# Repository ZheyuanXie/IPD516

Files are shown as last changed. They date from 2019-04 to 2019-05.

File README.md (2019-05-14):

# IPD 516 final project (MIDI & Sync Team)
Zheyuan Xie, Peng Li

## Overview
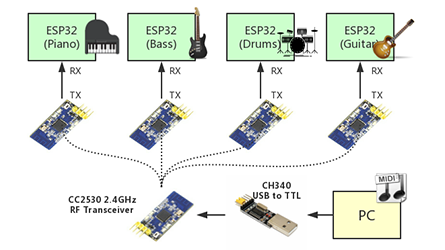
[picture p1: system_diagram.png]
system


## Software
### Dependency
 - pyserial
 - mido
 - remi
 
You can install these packages using pip:
```
pip install pyserial mido remi
```

## Hardware
 - The transmitter module connected to PC sends MIDI bytes to four receiver modules.
 - The receiver modules process the bytes and communicate with the machatronic instrument through a TTL serial interface.

MIDI Transmitter PCB          |  MIDI Receiver PCB
:-------------------------:|:-------------------------:
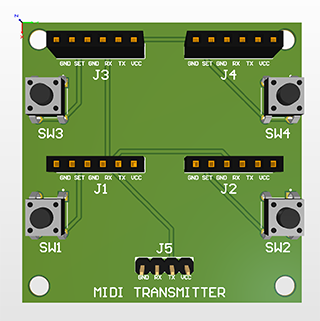
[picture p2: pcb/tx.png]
pcb_rx
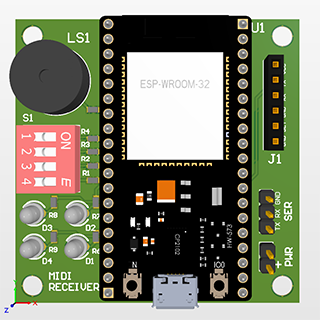
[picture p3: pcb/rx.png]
pcb_tx
      |  

## Instruction for Instrument Teams
As a musical instrument team, you will get a receiver module. You should connect the UART2 port (or another UART port) of your ESP32 to the SER connector (3 male header pins on the right side of the receiver module).

The code that runs on your ESP32 should be derived from `insturment_template.ino`. The four functions you will need to implement are:
 - `init_inst`: Initialize your instrument, run only once when system boots.
 - `note_on`: The response to a MIDI NOTE_ON message. Do not use blocking functions like `delay()` here.
 - `note_off`: The response to a MIDI NOTE_OFF message. Instrument that does not sustain need not to implement this function.
 - `expected_delay`: This function calculates the expected delay between executing the `note_on` and actually generating sound. It can be a constant or a function of note, velocity, and previous note played, depending on the type of your instrument.

The MIDI receiver module issues commands in real time, but in `instrument_template.ino`, each note is delayed `GLOBAL_DELAY - expected_delay()` microseconds to trigger the `note_on` function. The default value of `GLOBAL_DELAY` is **3 seconds**, which should give you enough time to prepare the actuator. Therefore the `expeteced_delay()` should not return a value larger than the `GLOBAL_DELAY`.

### Test your code with MIDI Receiver PCB using USB Serial
For instrument team who want to test their code that derived from `insturment_template.ino`, you should
- Upload `receiver_test.ino` to the ESP32 that will mount on the MIDI Receiver PCB;
- Connect your ESP32 to receiver ESP32;
- Set DIP switch *1* ON to receive message via USB serial;
- Set DIP switch *2* ON to turn the buzzer ON.

Instrument ESP32 | Receiver ESP32
:-----------------:|:----------------:
RX   |TX
TX   |RX
GND|GND
- Connect receiver ESP32 to your computer COM port
- Download `sender` folder and run the python code `main.py` 
- Choose the serial COM Port that receiver ESP32 connects to
- Choose the song that you would like to play
- Map channels as you desired, for example `2:0,9:9` means map MIDI channel 3 to instrument channel 0 and map MIDI channel 10 to instrument channel 9, this also means that only MIDI events from MIDI channel 3 and channel 10 are sent. If you want MIDI messages from all channel to be received, you need to write `0:0,1:1,2:2,3:3,4:4,5:5,6:6,7:7,8:8,9:9,10:10,11:11,12:12,13:13,14:14,15:15`. You can also map 2 or more channel to one channel, `0:0, 2:0` maps MIDI channel 1 and 3 to instrument channel 0.

Now when you hit the start button, the receiver ESP32 should get MIDI events via USB serial and should send MIDI events of channel selected by DIP switch to your instrument ESP32. DIP switch *3* is the most significant bit and *4* is the least significant bit. If *3* is *on*, then instrument channel 2 is selected. If *4* is on, then instrument channel 1 is selected. If *3* and *4* are both on, then instrument channel 3 is selected.

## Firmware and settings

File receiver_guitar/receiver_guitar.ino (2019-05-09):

 
#define PRINT_ERROR Serial.println("Error!");

#define LED_R 13
#define LED_Y 12
#define LED_G 27
#define LED_W 25
#define DIP_SWITCH_1 36
#define DIP_SWITCH_2 39
#define DIP_SWITCH_3 34
#define DIP_SWITCH_4 35
#define GLOBAL_DELAY 4500000  // global delay in microseconds

#include "esp_task_wdt.h"
#include "soc/timer_group_struct.h"
#include "soc/timer_group_reg.h"

//byte cmd[3];
int cnt = 0;
int count =0;
/* structure that hold data*/
typedef struct{
  byte info[3];
  unsigned long receivedTime;
}midiMes;

typedef struct{
  byte note;
  unsigned long receivedOnTime;
}midiMes_guitar;

/* msg queue */
#define MSG_Q_SIZE 128
uint8_t msg_q_bmap[MSG_Q_SIZE];

midiMes cmd;

/* this variable hold queue handle */
xQueueHandle xQueue;
TaskHandle_t xTask1;
TaskHandle_t xTask2;

void setup() {
  memset(msg_q_bmap, 0, sizeof(msg_q_bmap));
  
  Serial.begin(115200);
  Serial1.begin(115200,SERIAL_8N1,26,14);
  Serial2.begin(115200);
  ledcSetup(0, 2000, 8);
  ledcAttachPin(32, 0);
  
  pinMode(LED_R, OUTPUT);
  pinMode(LED_Y, OUTPUT);
  pinMode(LED_G, OUTPUT);
  pinMode(LED_W, OUTPUT);
  pinMode(DIP_SWITCH_1, INPUT);
  pinMode(DIP_SWITCH_2, INPUT);
  pinMode(DIP_SWITCH_3, INPUT);
  pinMode(DIP_SWITCH_4, INPUT);
  
  /* create the queue which size can contains 5 elements of Data */
  xQueue = xQueueCreate(2000, (sizeof(midiMes)));

//  xTaskCreatePinnedToCore(
//      sendTask,           /* Task function. */
//      "sendTask",        /* name of task. */
//      2000,                    /* Stack size of task */
//      NULL,                     /* parameter of the task */
//      1,                        /* priority of the task */
//      &xTask1,                /* Task handle to keep track of created task */
//      1);                    /* pin task to core 0 */
  xTaskCreatePinnedToCore(
      receiveTask,           /* Task function. */
      "receiveTask",        /* name of task. */
      20000,                    /* Stack size of task */
      NULL,                     /* parameter of the task */
      1,                        /* priority of the task */
      &xTask2,            /* Task handle to keep track of created task */
      0);                 /* pin task to core 1 */
}

void loop() {
  if (digitalRead(DIP_SWITCH_1)) {
    digitalWrite(2,HIGH);
    if (Serial.available() > 0) {
      process_incoming_byte(Serial.read());
    }
  } else {
    digitalWrite(2,LOW);
    if (Serial2.available() > 0) {
      process_incoming_byte(Serial2.read()); 
    }
  }    
}

//void sendTask( void * parameter )
//{
//  for(;;){
//    if (Serial2.available() > 0) {
//      Serial.println(Serial2.read());
//      process_incoming_byte(Serial2.read());
//    }
//  }
//}

void receiveTask( void * parameter )
{
  BaseType_t xStatus;
  for(;;)
  {
    midiMes receivedCmd;
  /* keep the status of receiving data */  
    /* receive data from the queue */
    xStatus = xQueueReceive( xQueue, &receivedCmd, 10);
    /* check whether receiving is ok or not */
    if(xStatus == pdPASS){  
      while ((micros() - receivedCmd.receivedTime)<GLOBAL_DELAY){
        //feed the dog
        TIMERG0.wdt_wprotect=TIMG_WDT_WKEY_VALUE;
        TIMERG0.wdt_feed=1;
        TIMERG0.wdt_wprotect=0;
      };        
      process_midi_command(receivedCmd.info);
    }
  }  
  vTaskDelete( NULL );
}

void process_incoming_byte(const byte incoming_byte) {
  if ((uint8_t)incoming_byte > 127) {
    cnt = 0;
    cmd.info[cnt] = (incoming_byte & 0x0f);
  } else if (cnt > 3) {
    PRINT_ERROR;
  } else {
    cnt++;
    cmd.info[cnt] = incoming_byte;
    if (cnt == 2) {
      cmd.receivedTime = micros();
      xQueueSendToBack(xQueue, &cmd, 10);
      if (cmd.info[0] == get_channel()){
        storeInSendQueue();
//        cmd.info[1] = (cmd.info[1] | 0x80);
//        Serial1.write(cmd.info[1]); 
      }
    }
  }
}

midiMes_guitar sendQueue[MSG_Q_SIZE];

int length = 0;
int msg_q_ptr = 0;
byte duration_buf[5];
unsigned long duration;

void storeInSendQueue(){
  if (cmd.info[2]>0){
    for (int i = 0; i <= MSG_Q_SIZE; i++) {
      if (msg_q_bmap[i] == 0) {
        msg_q_bmap[i] = 1;
        sendQueue[i].note = cmd.info[1];
        sendQueue[i].receivedOnTime = micros(); 
        length++;
        break;  
      }else if (i == MSG_Q_SIZE - 1){
//          Serial.printf("Error: message queue is full!\n");
          break;
      }
    }
  }else{
    for(int i = 0; i <= MSG_Q_SIZE; i++)
      if (msg_q_bmap[i] == 1 && sendQueue[i].note == cmd.info[1]) {
        duration = micros() - sendQueue[i].receivedOnTime;
        duration_buf[0] = sendQueue[i].note | 0x80;
        duration_buf[1] = (unsigned long)duration & 0x7F;
        duration_buf[2] = ((unsigned long)duration >> 7)  & 0x7F;
        duration_buf[3] = ((unsigned long)duration >> 14) & 0x7F;
        duration_buf[4] = ((unsigned long)duration >> 21) & 0x7F;
        duration_buf[5] = ((unsigned long)duration >> 28) & 0x7F; 
        Serial1.write(duration_buf,6);      
//        Serial1.write(duration_buf[0]);
//        Serial1.write(duration_buf[1]);
//        Serial1.write(duration_buf[2]);
//        Serial1.write(duration_buf[3]);
//        Serial1.write(duration_buf[4]);
//        Serial1.write(duration_buf[5]);
        msg_q_bmap[i] = 0;
        break;
        length--;  
      }else if (i == MSG_Q_SIZE - 1){
//          Serial.printf("Error: message queue is full!\n");
          break;
      }       
  }
}

uint8_t get_channel() {
  uint8_t res = digitalRead(DIP_SWITCH_3) * 2 + digitalRead(DIP_SWITCH_4);
//  Serial.printf("DIP SWITCH: %d\n", res);
  return res;
}

void process_midi_command(byte MIDI[3]) {
  count = count +1;
  Serial.printf("channel:%d, note:%d, velocity:%d， #get%d.\n\r", MIDI[0], MIDI[1], MIDI[2],count);
  uint8_t channel = MIDI[0];
  uint8_t note = MIDI[1];
  uint8_t vel = MIDI[2];

  // Drumset
  if (channel == 9) {
    if (note > 42 && vel > 0) digitalWrite(LED_R, HIGH);
    if (note > 42 && vel == 0) digitalWrite(LED_R, LOW);
    if (note == 36 && vel > 0) digitalWrite(LED_G, HIGH);
    if (note == 36 && vel == 0) digitalWrite(LED_G, LOW);
    if (note == 40 && vel > 0) digitalWrite(LED_Y, HIGH);
    if (note == 40 && vel == 0) digitalWrite(LED_Y, LOW);
    if (note == 42 && vel > 0) digitalWrite(LED_W, HIGH);
    if (note == 42 && vel == 0) digitalWrite(LED_W, LOW);
  }

  // selected channel
  if (channel == get_channel() && digitalRead(DIP_SWITCH_2)) {
    if (vel > 0) {
      ledcWriteTone(0, note_to_frequency(note));
    } else {
      ledcWriteTone(0, 0);
    }
  }
}

int note_to_frequency(uint8_t note) {
  switch (note) {
    case 36: return 65;
    case 37: return 69;
    case 38: return 73;
    case 39: return 78;
    case 40: return 82;
    case 41: return 87;
    case 42: return 93;
    case 43: return 98;
    case 44: return 104;
    case 45: return 110;
    case 46: return 117;
    case 47: return 123;
    case 48: return 131;
    case 49: return 139;
    case 50: return 147;
    case 51: return 156;
    case 52: return 165;
    case 53: return 175;
    case 54: return 185;
    case 55: return 196;
    case 56: return 207;
    case 57: return 220;
    case 58: return 233;
    case 59: return 247;
    case 60: return 262;
    case 61: return 277;
    case 62: return 294;
    case 63: return 311;
    case 64: return 330;
    case 65: return 349;
    case 66: return 370;
    case 67: return 392;
    case 68: return 415;
    case 69: return 440;
    case 70: return 466;
    case 71: return 494;
    case 72: return 523;
    case 73: return 554;
    case 74: return 587;
    case 75: return 622;
    case 76: return 659;
    case 77: return 698;
    case 78: return 740;
    case 79: return 784;
    case 80: return 831;
    case 81: return 880;
    case 82: return 932;
    case 83: return 988;
    case 84: return 1046;
    case 85: return 1109;
    case 86: return 1175;
    case 87: return 1245;
    case 88: return 1319;
    case 89: return 1397;
    case 90: return 1480;
    case 91: return 1568;
    case 92: return 1661;
    case 93: return 1760;
    case 94: return 1865;
    case 95: return 1976;
    case 96: return 2093;
    case 97: return 2217;
    case 98: return 2349;
    case 99: return 2489;
    case 100: return 2637;
    case 101: return 2794;
    case 102: return 2960;
    case 103: return 3136;
    case 104: return 3322;
    case 105: return 3520;
    case 106: return 3729;
    case 107: return 3951;
    case 108: return 4186;
    case 109: return 4435;
    case 110: return 4699;
    case 111: return 4978;
    case 112: return 5274;
    case 113: return 5588;
    case 114: return 5920;
    case 115: return 6272;
    case 116: return 6645;
    case 117: return 7040;
    case 118: return 7459;
    case 119: return 7902;
    case 120: return 8372;
    case 121: return 8870;
    case 122: return 9397;
    case 123: return 9956;
    case 124: return 10548;
    case 125: return 11175;
    case 126: return 11840;
    case 127: return 12544;
    default: return 0;
  }
}

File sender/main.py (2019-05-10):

import mido
import serial
import remi.gui as gui
from remi import start, App
import os
import threading
from multiprocessing import Process, Pipe
import ast
import socket

channel_map_table = {
    "BEATLES_THE_-_Octopus_s_garden-mod.mid":"5:0,2:1,4:2,9:3",
    "Foreplay_From_Long_Time-mhy.mid":"0:0,1:1,4:2,9:3",
    "John Lee Hooker - Boom Boom Boom-final.mid":"0:0,1:1,8:2,9:3",
    "Led_Zeppelin_-_Good_Times_Bad_Times mod.mid":"?",
    "Scorpions_-_Rock_You_Like_a_Hurricane.mid":"0:0,1:0,6:1,2:2,3:2,9:3",
    "FoolInTheRainOneString.mid":"1:0,2:1,0:2,9:3",
    "FoolInTheRainfinal2.mid":"1:0,2:1,0:2,9:3"
}

try:
    os.listdir("song")
    SONG_DIR = "song/"
except:
    SONG_DIR = "sender/song/"


def midi_process(filename, com_port, pipe, channel_map):
    # print(channel_map)
    try:
        ser = serial.Serial(com_port, baudrate=115200)  # open serial port
    except Exception:
        print("Error Opening Serial.")
        ser = None
        return
    # print("midi process starting")

    mid = mido.MidiFile(SONG_DIR + filename)

    length = mid.length
    time = 0.0
    for msg in mid.play():
        time = time + msg.time
        if (msg.type == "note_on"):
            if (msg.channel == 9):
                b = bytearray([msg.channel | 0x80, msg.note, msg.velocity])
                ser.write(b)
            mapped_ch = channel_map.get(msg.channel)
            if mapped_ch is not None:
                # print("send")
                pipe.send([mapped_ch, msg.note, msg.velocity, time, 1000*(time/length)])
                b = bytearray([mapped_ch | 0x80, msg.note, msg.velocity])
                # print(b)
                ser.write(b)
        if (msg.type == "note_off"):
            if mapped_ch is not None:
                # print("send")
                pipe.send([mapped_ch, msg.note, 0, time, 1000*(time/length)])
                b = bytearray([mapped_ch | 0x80, msg.note, 0])
                # print(b)
                ser.write(b)
    return

class MyApp(App):
    def __init__(self, *args):
        super(MyApp, self).__init__(*args)
    
    def onresize(self, emitter, w, h):
        # print(emitter, w, h)
        if int(w) > 450:
            self.container.set_size(450, 300)
        else:
            self.container.set_size(int(w), int(int(w)*(2.0/3.0)))

    def main(self):
        container = gui.VBox(width='450px', height='300px')

        # Title
        self.lbl = gui.Label("Prof. Yim's Robotic Band")
        self.lblX = gui.Label("(X)")
        self.lblX.onclick.connect(self.btn_exited)
        self.lbl.style['font-size'] = '20px'
        container.append(gui.HBox([self.lbl, self.lblX]))

        # Serial Port Selection
        self.select_port_hbox = gui.HBox(width='100%')
        self.select_port_hbox.style['font-size'] = '16px'
        self.select_port_label = gui.Label('Select Port:', width='40%')
        self.select_port_dropdown = gui.DropDown()
        # self.select_port_refresh_btn = gui.Button(text='R', width='10%', height='80%')
        self.port_list = ['COM%s' % (i + 1) for i in range(16)]
        for port in self.port_list:
            try:
                ser = serial.Serial(port, baudrate=115200)  # open serial port
                ser.close()
                self.select_port_dropdown.append(port)
            except Exception:
                pass
        self.select_port_hbox.append(self.select_port_label)
        self.select_port_hbox.append(self.select_port_dropdown)
        # self.select_port_hbox.append(self.select_port_refresh_btn)
        container.append(self.select_port_hbox)

        # Music Selection
        self.select_music_hbox = gui.HBox(width='100%')
        self.select_music_hbox.style['font-size'] = '16px'
        self.select_music_label = gui.Label('Select Music:', width='40%')
        self.select_music_dropdown = gui.DropDown()
        # self.select_music_refresh_btn = gui.Button(text='R', width='10%', height='80%')
        self.music_list = []
        for filename in os.listdir(SONG_DIR):
            if not os.path.isdir(SONG_DIR+filename):
                self.music_list.append(gui.DropDownItem(filename))
                self.select_music_dropdown.append(self.music_list[-1])
        self.select_music_hbox.append(self.select_music_label)
        self.select_music_hbox.append(self.select_music_dropdown)
        # self.select_music_hbox.append(self.select_music_refresh_btn)
        container.append(self.select_music_hbox)
        self.select_music_dropdown.onchange.connect(self.update_channel_assignment)

        # channel mapping
        channel_map_Hbox = gui.HBox(width='100%')
        channel_map_Hbox.style['font-size'] = '16px'
        self.channel_map_textbox = gui.TextInput()
        self.channel_map_textbox.set_value("0:0,1:1,2:2,3:3,4:4,5:5,6:6,7:7,8:8,9:9")
        channel_map_Hbox.append([gui.Label("CH Map:", width='40%'), self.channel_map_textbox])
        container.append(channel_map_Hbox)

        # Play/Stop Button
        self.bt = gui.Button('Start', width = '50%', height = '50px')
        self.bt.onclick.connect(self.btn_pressed)
        self.bt.style['font-size'] = '25px'
        container.append(self.bt)

        # Play Information
        self.info = gui.Label('-')
        container.append(self.info)
        self.progress = gui.Progress(_max=1000, width='100%')
        container.append(self.progress)
        self.table = gui.TableWidget(5, 4, True, True, width='100%')
        self.table.style['font-size'] = '14px'
        self.table.style['align-items'] = 'center'   # TODO: text alignment
        self.table.item_at(0,0).set_text("Channel")
        self.table.item_at(0,1).set_text("Note")
        self.table.item_at(0,2).set_text("Velocity")
        self.table.item_at(0,3).set_text("Time")
        # for i in range(4):
        #     self.table.item_at(i+1, 0).set_text("%d"%(i))
        self.table.item_at(1,0).set_text("CH0 - Piano")
        self.table.item_at(2,0).set_text("CH1 - Bass")
        self.table.item_at(3,0).set_text("CH2 - Guitar")
        self.table.item_at(4,0).set_text("CH3 - Drum")
        container.append(self.table)
        
        # MIDI Parser Thread
        self.mprocess = None
        self.mthread = None
        self.is_playing = False
        self.pipe = None

        # returning the root widget
        self.container = container
        self.server_close = False
        return self.container

    def btn_exited(self,widget):
        self.server_close = True
        self.close()
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

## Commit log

2019-04-01 on_close terminate midi thread, add table view
2019-04-17 dip switch support
2019-04-18 Add PCBs
    [1825910-6.PcbLib, 1825910-6.SchLib, Buzzer.SchLib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]
2019-04-29 dip switch debug mode
2019-05-09 change global delay, dip switch behavior
